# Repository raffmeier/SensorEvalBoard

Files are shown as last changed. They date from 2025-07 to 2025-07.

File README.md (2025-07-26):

# Sensor Evaluation Board

## Overview

These are the KiCad files for a simple sensor evaluation board. It features an STM32F4 MCU, an IMU (BMI088), a magnetometer (LIS3MDLTR) and a barometer (BMP390). All sensors are connected to the same I2C interface on the microcontroller. The board is powered by the USB-C port and can be programmed via the SWD pins which are placed on the connector to interface with an ST-LINK V3MINIE (UART1 is routed to STLINK). Additionaly the STM32 could be programmed via the USB cable in DFU mode by setting the BOOT0 jumper to high. The board features some extra GPIO (e.g. the sensor I2C bus, UART2) headers and two controllable LEDs.

## Pictures

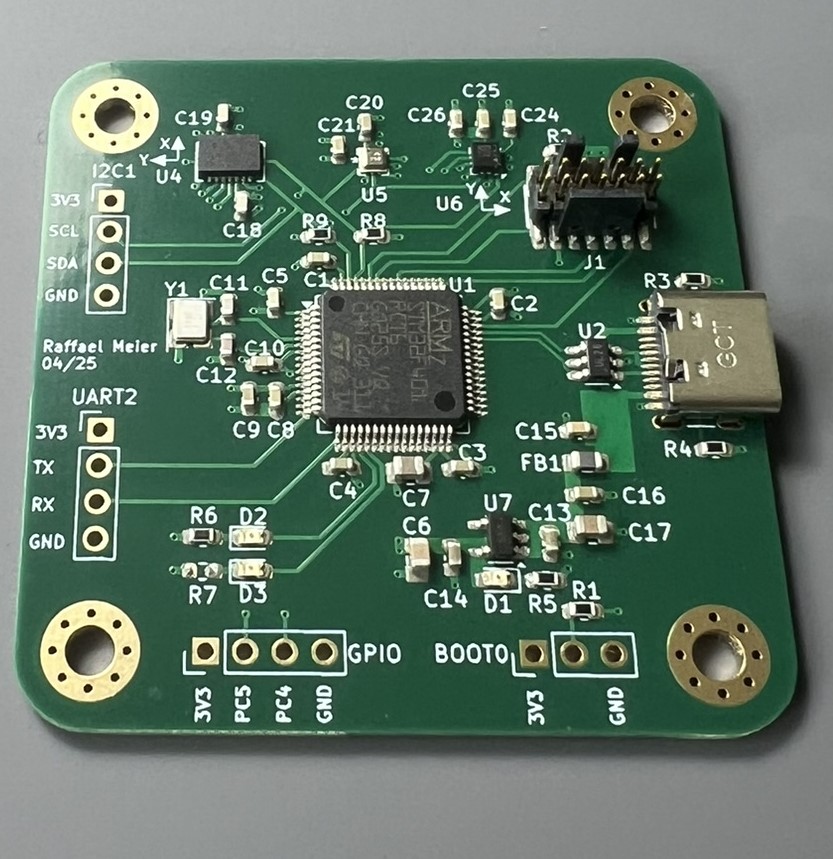
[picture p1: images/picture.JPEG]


PCB after SMD soldering.

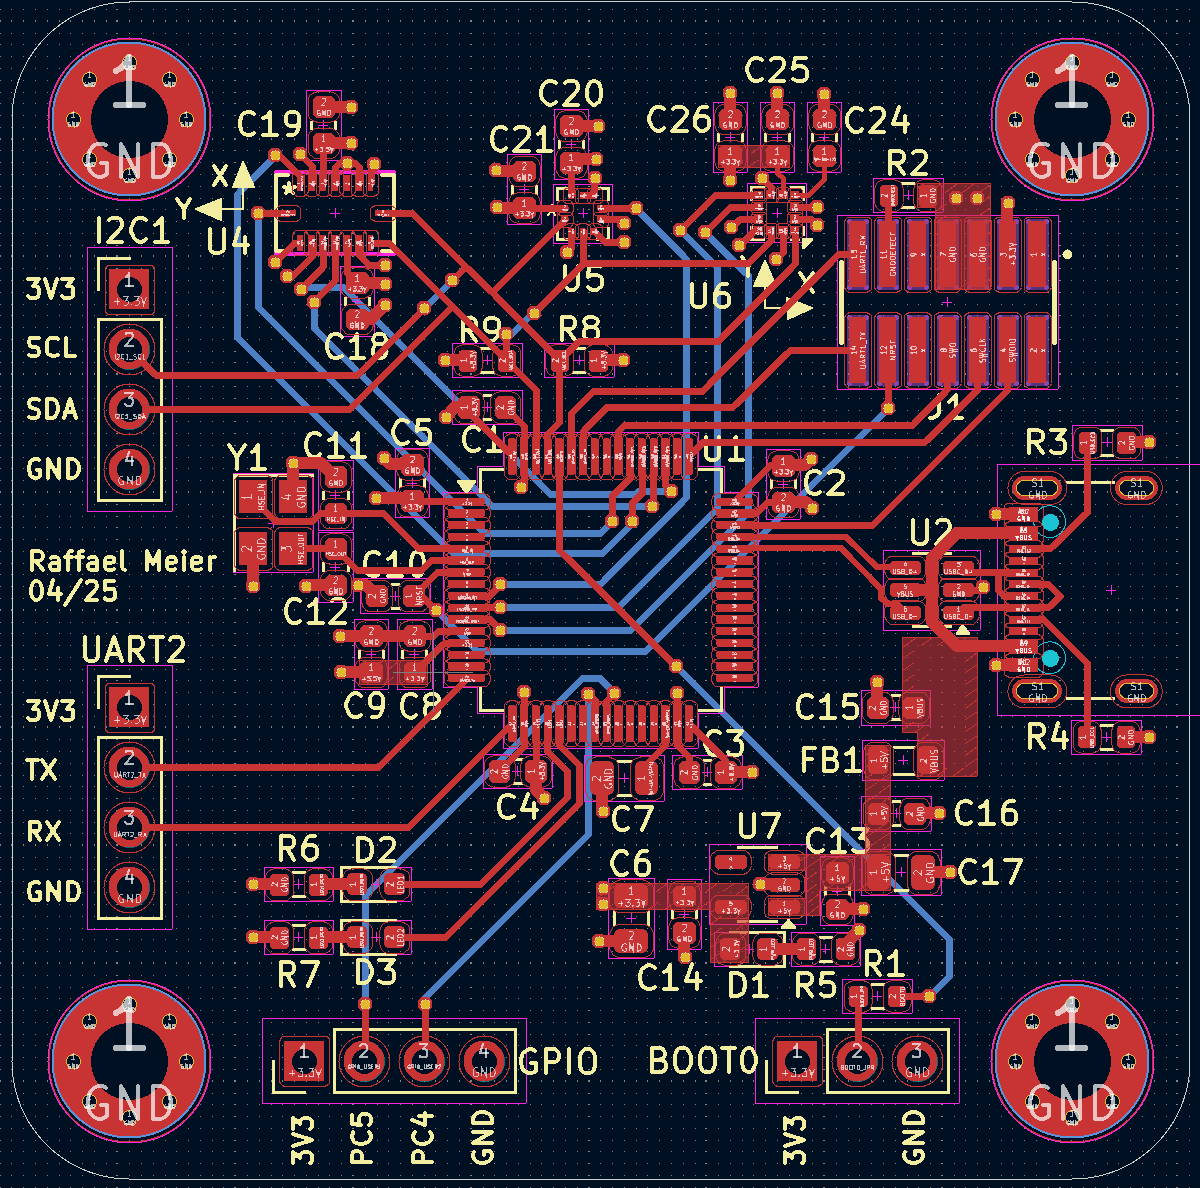
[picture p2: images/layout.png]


Layout of the PCB. Build-Up: SGN-GND-3V3-SGN

## BOM
- STM32F401RCT6 (1)
- BMI088 (1)
- LIS3MDLTR (1)
- BMP390 (1)
- 10p 0603 cap (2)
- 10n 0603 cap (1)
- 100n 0603 cap (14)
- 1u 0603 cap (4)
- 4.7u 0805 cap (2)
- 10u 0805 cap (1)
- Red SMD LED 0603 (3)
- Ferrite bead 600 ohm 0805 (e.g. HZ0805E601R-10) (1)
- 100 resistor 0603 (1)
- 510 resistor 0603 (3)
- 5.1k resistor (4)
- 10k resistor 0603 (1)
- USB-C USB2.0 receptacle (e.g. USB4105-GF-A) (1)
- FTSH-107-01-L-DV-KCONN HEADER SMD 14POS 1.27MM Samtec Inc. (1)
- USB TVS diode STMicroelectronics USBLC6-2SC6 (1)
- Linear regulator SOT23-5 (e.g. MIC5504-3.3YM5-TR) (1)
- 16MHz oscillator TSX-3225 16.0000MF09Z-AC0 (1)

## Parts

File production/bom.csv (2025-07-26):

Designator | Footprint | Quantity | Value | LCSC Part #
BARO | BMP390 | 1 | BMP390 | C2684802
C1, C10, C16, C18, C19, C2, C20, C21, C24, C25, C3, C4, C5, C8 | 0603 | 14 | 100n
C11, C12 | 0603 | 2 | 10p
C13, C14, C9 | 0603 | 3 | 1u
C15 | 0603 | 1 | 10n
C17, C7 | 0805 | 2 | 4u7
C26 | 0603 | 1 | 1u
C6 | 0805 | 1 | 10u
FB1 | 0805 | 1 | FerriteBead | C1017
IMU | QFN_BMI085_BOS | 1 | BMI088 | C194919
J2 | PinHeader_1x03_P2.54mm_Vertical | 1 | Conn_01x03
J3 | USB_C_Receptacle_G-Switch_GT-USB-7010ASV | 1 | USB_C_Receptacle_USB2.0_16P | C393939
J4, J5, J6 | PinHeader_1x04_P2.54mm_Vertical | 3 | Conn_01x04
LED1, LED2, PWR | 0603 | 3 | RED | C2286
MAG | LGA-12_2x2mm_P0.5mm | 1 | LIS3MDL
R1 | 0603 | 1 | 10k
R2 | 0603 | 1 | 100
R3, R4 | 0603 | 2 | 5k1
R5, R6, R7 | 0603 | 3 | 510
R8, R9 | 0603 | 2 | 4k7
STLINK | SAMTEC_FTSH-107-01-F-DV-K | 1 | Conn_02x07_Odd_Even | C7465995
U1 | LQFP-64_10x10mm_P0.5mm | 1 | STM32F401RCT6 | C74524
U2 | SOT-23-6 | 1 | USBLC6-2SC6
U3 | SOT-23-3 | 1 | XC6206P332MR-G | C5446
Y1 | Crystal_SMD_3225-4Pin_3.2x2.5mm | 1 | Crystal_GND24 | C13738

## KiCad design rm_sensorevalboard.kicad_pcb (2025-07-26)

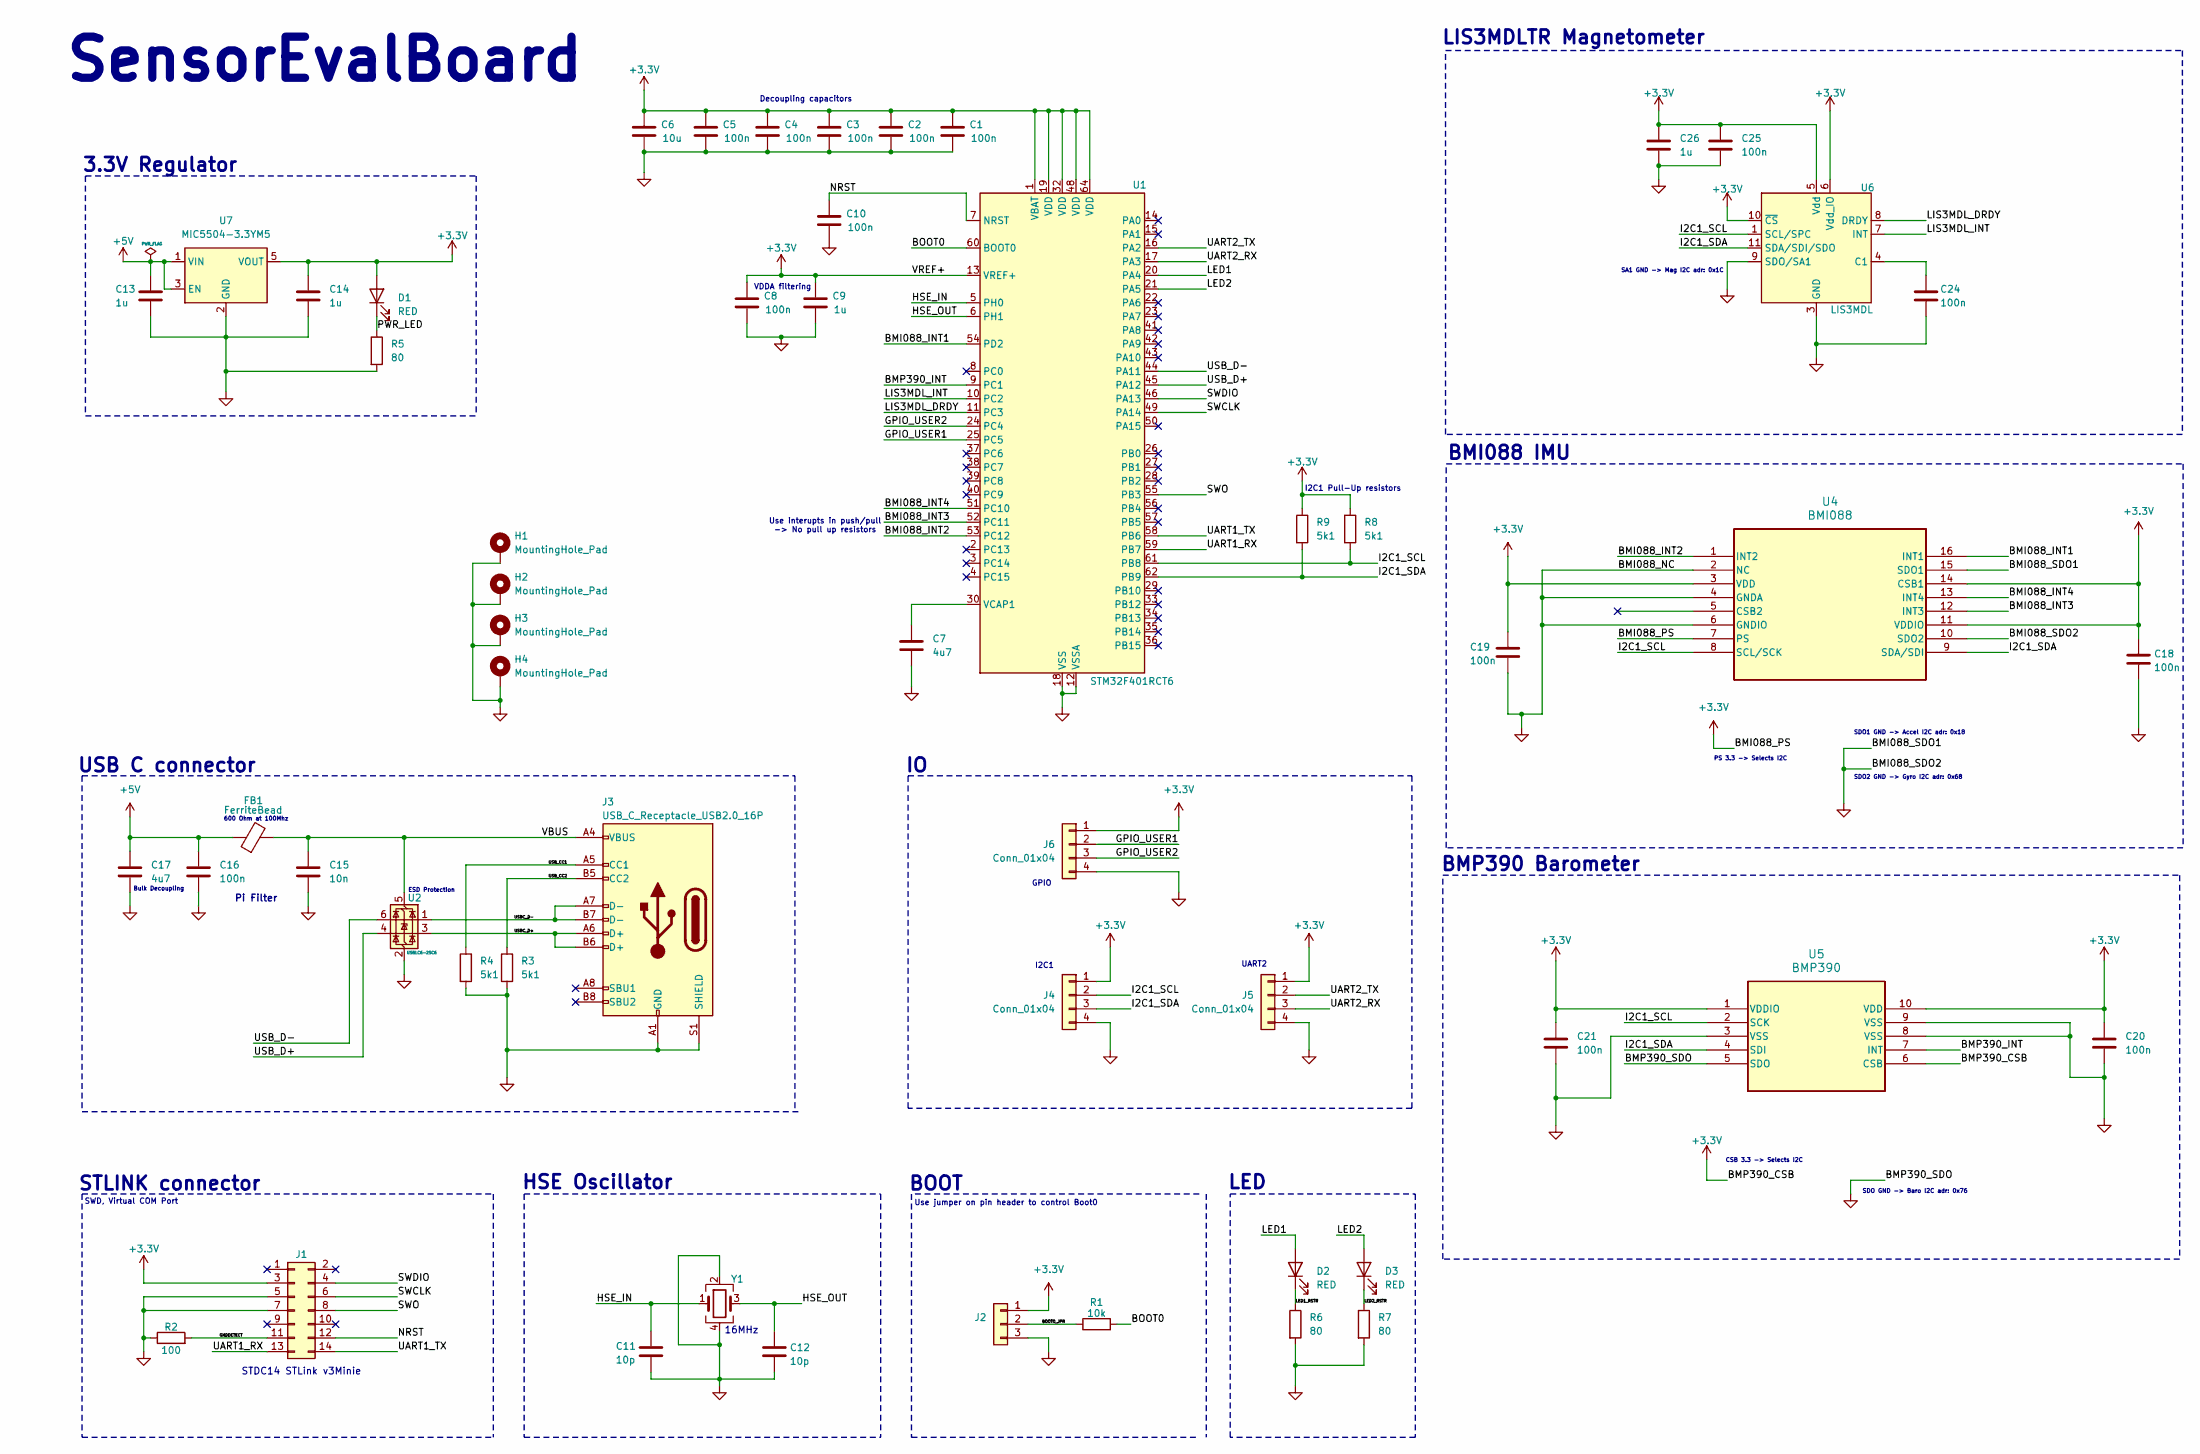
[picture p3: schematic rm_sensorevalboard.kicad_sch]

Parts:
C1, C2, C3, C4, C5, C8, C10, C16, C18, C19, C20, C21, C24, C25: 100n; C_0603_1608Metric
C6: 10u; C_0805_2012Metric
C7, C17: 4u7; C_0805_2012Metric
C9, C13, C14, C26: 1u; C_0603_1608Metric
C11, C12: 10p; C_0603_1608Metric
C15: 10n; C_0603_1608Metric
D1, D2, D3: RED; LED_0603_1608Metric; LCSC Part # C2286
FB1: FerriteBead; L_0805_2012Metric; LCSC Part # C1017
H1, H2, H3, H4: MountingHole_Pad; MountingHole_3.2mm_M3_Pad_Via
J1: Conn_02x07_Odd_Even; SAMTEC_FTSH-107-01-F-DV-K; LCSC Part # C7465995
J2: Conn_01x03; PinHeader_1x03_P2.54mm_Vertical
J3: USB_C_Receptacle_USB2.0_16P; USB_C_Receptacle_G-Switch_GT-USB-7010ASV; LCSC Part # C393939
J4, J5, J6: Conn_01x04; PinHeader_1x04_P2.54mm_Vertical
R1: 10k; R_0603_1608Metric
R2: 100; R_0603_1608Metric
R3, R4, R8, R9: 5k1; R_0603_1608Metric
R5, R6, R7: 80; R_0603_1608Metric
U1: STM32F401RCT6; LQFP-64_10x10mm_P0.5mm; LCSC Part # C74524
U2: USBLC6-2SC6; SOT-23-6
U4: BMI088; QFN_BMI085_BOS; LCSC Part # C194919
U5: BMP390; LCSC Part # C2684802
U6: LIS3MDL; LGA-12_2x2mm_P0.5mm
U7: MIC5504-3.3YM5; SOT-23-5
Y1: Crystal_GND24; Crystal_SMD_3225-4Pin_3.2x2.5mm; LCSC Part # C13738

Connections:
+3.3V: C1.1, C2.1, C3.1, C4.1, C5.1, C6.1, C8.1, C9.1, C14.1, C18.1, C19.1, C20.1, C21.1, C25.1, C26.1, D1.2 (A), J1.3, J2.1, J4.1, J5.1, J6.1, R8.1, R9.1, U1.1 (VBAT), U1.13 (VREF+), U1.19 (VDD), U1.32 (VDD), U1.48 (VDD), U1.64 (VDD), U4.3 (VDD), U4.7 (PS), U4.11 (VDDIO), U4.14 (CSB1), U5.1 (VDDIO), U5.6 (CSB), U5.10 (VDD), U6.5 (Vdd), U6.6 (Vdd_IO), U6.10 (~CS), U7.5 (VOUT)
+5V: C13.1, C16.1, C17.1, FB1.1, U7.1 (VIN), U7.3 (EN)
/BMI088_INT1: U1.54 (PD2), U4.16 (INT1)
/BMI088_INT2: U1.53 (PC12), U4.1 (INT2)
/BMI088_INT3: U1.52 (PC11), U4.12 (INT3)
/BMI088_INT4: U1.51 (PC10), U4.13 (INT4)
/BMP390_INT: U1.9 (PC1), U5.7 (INT)
/BOOT0: R1.2, U1.60 (BOOT0)
/BOOT0_JPR: J2.2, R1.1
/GNDDETECT: J1.11, R2.2
/GPIO_USER1: J6.2, U1.25 (PC5)
/GPIO_USER2: J6.3, U1.24 (PC4)
/HSE_IN: C11.1, U1.5 (PH0), Y1.1
/HSE_OUT: C12.1, U1.6 (PH1), Y1.3
/I2C1_SCL: J4.2, R8.2, U1.61 (PB8), U4.8 (SCL/SCK), U5.2 (SCK), U6.1 (SCL/SPC)
/I2C1_SDA: J4.3, R9.2, U1.62 (PB9), U4.9 (SDA/SDI), U5.4 (SDI), U6.11 (SDA/SDI/SDO)
/LED1: D2.2 (A), U1.20 (PA4)
/LED1_RSTR: D2.1 (K), R6.1
/LED2: D3.2 (A), U1.21 (PA5)
/LED2_RSTR: D3.1 (K), R7.1
/LIS3MDL_DRDY: U1.11 (PC3), U6.8 (DRDY)
/LIS3MDL_INT: U1.10 (PC2), U6.7 (INT)
/NRST: C10.1, J1.12, U1.7 (NRST)
/PWR_LED: D1.1 (K), R5.1
/SWCLK: J1.6, U1.49 (PA14)
/SWDIO: J1.4, U1.46 (PA13)
/SWO: J1.8, U1.55 (PB3)
/UART1_RX: J1.13, U1.59 (PB7)
/UART1_TX: J1.14, U1.58 (PB6)
/UART2_RX: J5.3, U1.17 (PA3)
/UART2_TX: J5.2, U1.16 (PA2)
/USBC_D+: J3.A6 (D+), J3.B6 (D+), U2.3 (I/O2)
/USBC_D-: J3.A7 (D-), J3.B7 (D-), U2.1 (I/O1)
/USB_CC1: J3.A5 (CC1), R4.1
/USB_CC2: J3.B5 (CC2), R3.1
/USB_D+: U1.45 (PA12), U2.4 (I/O2)
/USB_D-: U1.44 (PA11), U2.6 (I/O1)
/VBUS: C15.1, FB1.2, J3.A4 (VBUS), J3.A9 (VBUS), J3.B4 (VBUS), J3.B9 (VBUS), U2.5 (VBUS)
GND: C1.2, C2.2, C3.2, C4.2, C5.2, C6.2, C7.2, C8.2, C9.2, C10.2, C11.2, C12.2, C13.2, C14.2, C15.2, C16.2, C17.2, C18.2, C19.2, C20.2, C21.2, C24.2, C25.2, C26.2, H1.1, H2.1, H3.1, H4.1, J1.5, J1.7, J2.3, J3.A1 (GND), J3.A12 (GND), J3.B1 (GND), J3.B12 (GND), J3.S1 (SHIELD), J4.4, J5.4, J6.4, R2.1, R3.2, R4.2, R5.2, R6.2, R7.2, U1.12 (VSSA), U1.18 (VSS), U1.31 (VSS), U1.47 (VSS), U1.63 (VSS), U2.2 (GND), U4.2 (NC), U4.4 (GNDA), U4.6 (GNDIO), U4.10 (SDO2), U4.15 (SDO1), U5.3 (VSS), U5.5 (SDO), U5.8 (VSS), U5.9 (VSS), U6.2 (GND), U6.3 (GND), U6.9 (SDO/SA1), U6.12 (GND), U7.2 (GND), Y1.2, Y1.4
unnamed: C7.1, U1.30 (VCAP1)
unnamed: C24.1, U6.4 (C1)

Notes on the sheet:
SDO GND -> Baro I2C adr: 0x76
STDC14 STLink v3Minie
Decoupling capacitors
BOOT
600 Ohm at 100Mhz
LIS3MDLTR Magnetometer
I2C1
16MHz
SensorEvalBoard
STLINK connector
SDO2 GND -> Gyro I2C adr: 0x68
ESD Protection
HSE Oscillator
USB C connector
Bulk Decoupling
SDO1 GND -> Accel I2C adr: 0x18
GPIO
BMI088 IMU
VDDA filtering
BMP390 Barometer
Pi Filter
I2C1 Pull-Up resistors
SWD, Virtual COM Port
Use interupts in push/pull -> No pull up resistors
SA1 GND -> Mag I2C adr: 0x1C
UART2
CSB 3.3 -> Selects I2C
Use jumper on pin header to control Boot0
LED
3.3V Regulator
PS 3.3 -> Selects I2C

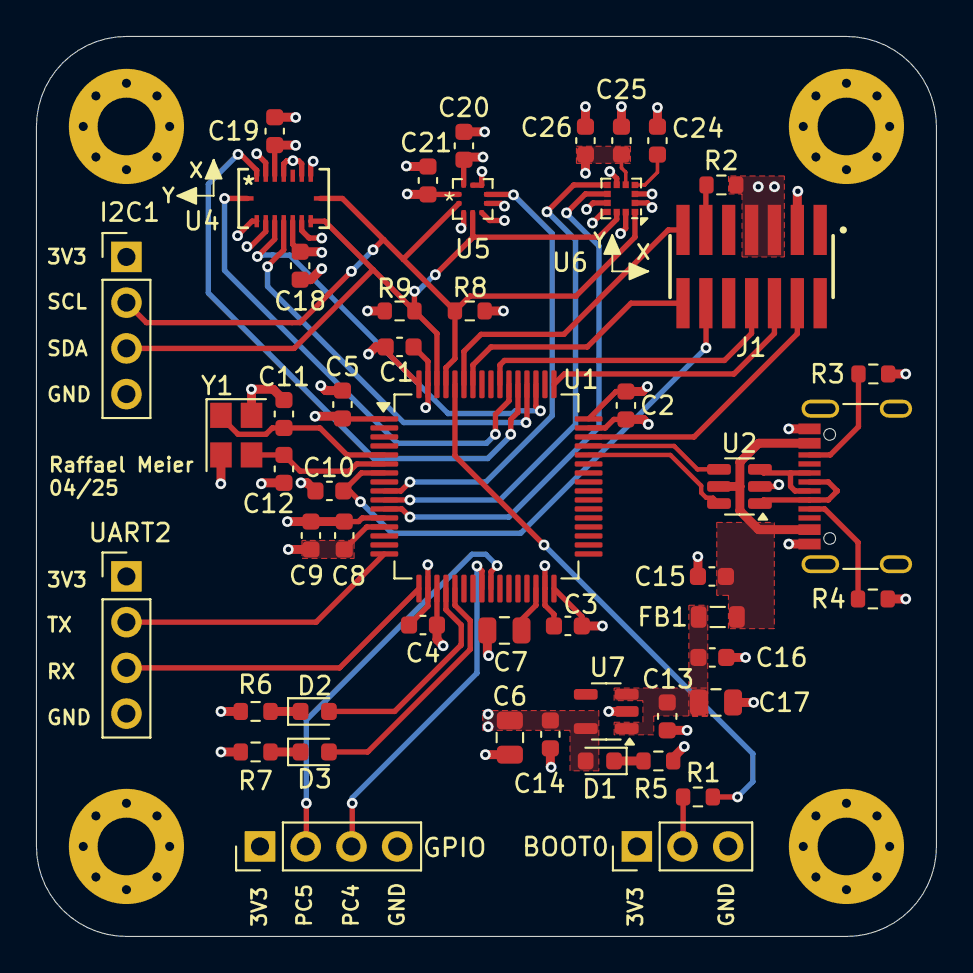
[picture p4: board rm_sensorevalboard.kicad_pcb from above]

Board: 4 copper layers, 50.0 x 50.0 mm, 54 parts (0 on the bottom side), 41 nets.
